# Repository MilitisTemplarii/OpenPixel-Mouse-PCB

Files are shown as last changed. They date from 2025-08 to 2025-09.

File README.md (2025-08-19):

# OpenPixel
# Mouse-PCB-STM32-PAW3395
BOM file soon :D

This is a mouse pcb based on stm32f215, usb3300 and paw3395

NO CODE, FIRMWARE, SOFTWARE, ETC, just a pcb design for hobby.

pcb1

pcb3

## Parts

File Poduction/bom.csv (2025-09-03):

Designator | Footprint | Quantity | Value | LCSC Part #
C1, C5, C7 | 805 | 3 | 10 uF
C2, C30, C31, C33, C38, C39, C4, C40, C41, C42, C43, C44, C45, C46, C48, C49, C50, C51, C52, C6, C8, C9 | 402 | 22 | 100 nF
C24, C25, C28, C29 | 402 | 4 | 1 µF
C26, C27 | 402 | 2 | 2.2 uF
C3, C47 | 603 | 2 | 4,7 uF
DEBUG1 | JST_PH_S4B-PH-K_1x04_P2.00mm_Horizontal | 1 | Conn_01x04_Pin
LED_DPI1 | LED_RGB_1210 | 1 | SB1210WC01-RGB
PAW3395 | PAW3395_LGA16_fixed | 1 | ~
R1 | 603 | 1 | 5,6 Ω
R10 | 603 | 1 | 330 Ω
R11 | 603 | 1 | 100 Ω
R12, R13 | 603 | 2 | 10 kΩ
R14 | 603 | 1 | 10 kΩ
R2, R6 | 603 | 2 | 22 Ω
R3, R7, R8 | 603 | 3 | 10kΩ
R4 | 603 | 1 | 12kΩ
R5 | 603 | 1 | 820Ω
R9 | 603 | 1 | 220 Ω
SCROLL1 | Encoder_Kailh_Wheel_3Pin | 1 | CEN981012R24
SW1, SW_DPI1 | SW_SPST_TL3342 | 2 | SW_Push
SW2 | SW_SPST_EVQP7C | 1 | SW_Push
SW_LAT1 | JST_SH_BM03B-SRSS-TB_1x03-1MP_P1.00mm_Vertical | 1 | Conn_01x03_Pin
SW_LEFT1, SW_RIGHT1, SW_WHEEL1 | SW_D2FC_OMR | 3 | SW_SPDT_321
SW_POLLING1 | SSSS213202_AAL | 1 | SSSS213202
U1 | SOT-23-5 | 1 | AP2112K-3.3
U2 | SOT-23-5 | 1 | TLV75519PDBV
U4 | LQFP-64_10x10mm_P0.5mm | 1 | STM32F215RGTx
U5 | QFN-32-1EP_5x5mm_P0.5mm_EP3.45x3.45mm | 1 | USB3300-EZK
USB1 | JST_PH_S5B-PH-K_1x05_P2.00mm_Horizontal | 1 | Conn_01x05_Pin
Y2 | Oscillator_SMD_24MHz_2.5x2.0mm | 1 | OT252024MJBA4SL
Y3 | Oscillator_SMD_8MHz_2.5x2.0mm | 1 | OT3EL89CJI-111YLC-8M

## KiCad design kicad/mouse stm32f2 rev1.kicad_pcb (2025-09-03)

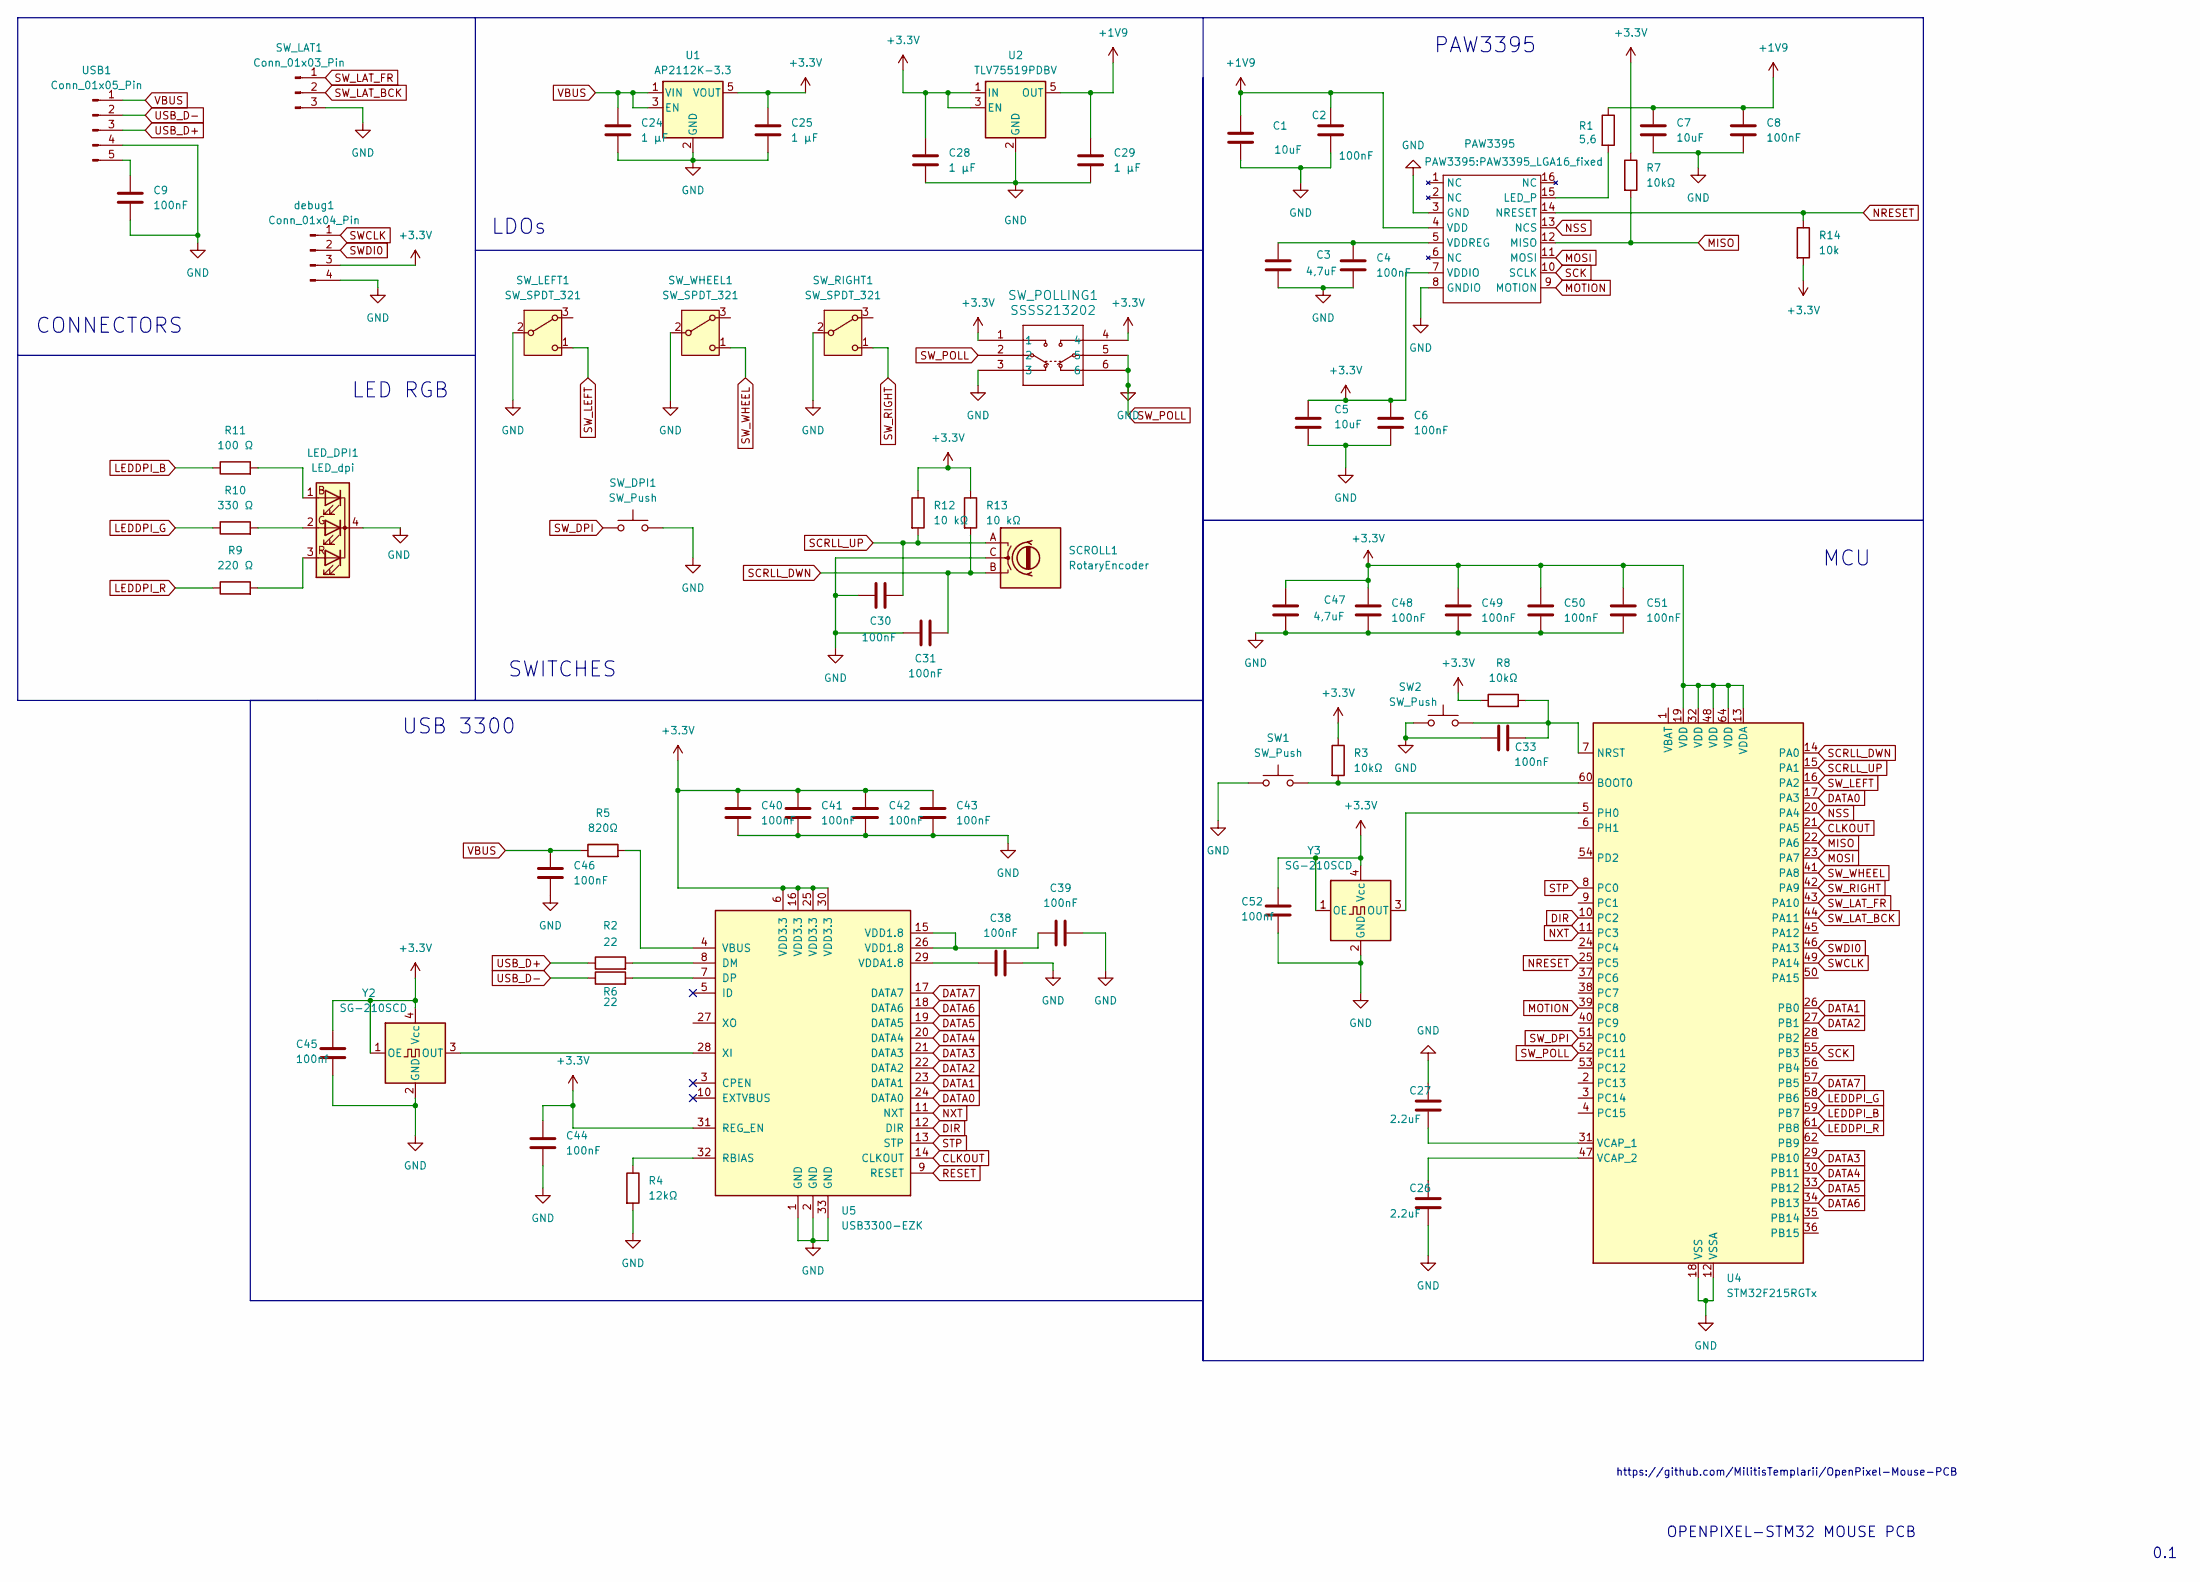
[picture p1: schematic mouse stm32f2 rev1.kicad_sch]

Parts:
C1, C5, C7: 10uF; C_0805_2012Metric
C2, C4, C6, C8, C9, C30, C31, C33, C38, C39, C40, C41, C42, C43, C44, C46, C48, C49, C50, C51: 100nF; C_0402_1005Metric
C3, C47: 4,7uF; C_0603_1608Metric
C24, C25, C28, C29: 1 µF; C_0402_1005Metric
C26, C27: 2.2uF; C_0402_1005Metric
C45, C52: 100nf; C_0402_1005Metric
LED_DPI1: LED_dpi; LED_RGB_1210
PAW3395: PAW3395_LGA16_fixed
R1: 5,6; R_0603_1608Metric
R2, R6: 22; R_0603_1608Metric
R3, R7, R8: 10kΩ; R_0603_1608Metric
R4: 12kΩ; R_0603_1608Metric
R5: 820Ω; R_0603_1608Metric
R9: 220 Ω; R_0603_1608Metric
R10: 330 Ω; R_0603_1608Metric
R11: 100 Ω; R_0603_1608Metric
R12, R13: 10 kΩ; R_0603_1608Metric
R14: 10k; R_0603_1608Metric
SCROLL1: RotaryEncoder; Encoder_Kailh_Wheel_3Pin
SW1: SW_Push; SW_SPST_TL3342
SW2: SW_Push; SW_SPST_EVQP7C
SW_DPI1: SW_Push; SW_SPST_TL3342
SW_LAT1: Conn_01x03_Pin; JST_SH_BM03B-SRSS-TB_1x03-1MP_P1.00mm_Vertical
SW_LEFT1: SW_SPDT_321; SW_D2FC_OMR
SW_POLLING1: SSSS213202; SSSS213202_AAL
SW_RIGHT1: SW_SPDT_321; SW_D2FC_OMR
SW_WHEEL1: SW_SPDT_321; SW_D2FC_OMR
U1: AP2112K-3.3; SOT-23-5
U2: TLV75519PDBV; SOT-23-5
U4: STM32F215RGTx; LQFP-64_10x10mm_P0.5mm
U5: USB3300-EZK; QFN-32-1EP_5x5mm_P0.5mm_EP3.45x3.45mm
USB1: Conn_01x05_Pin; JST_PH_S5B-PH-K_1x05_P2.00mm_Horizontal
Y2, Y3: SG-210SCD; Oscillator_SMD_SeikoEpson_SG210-4Pin_2.5x2.0mm
debug1: Conn_01x04_Pin; JST_PH_S4B-PH-K_1x04_P2.00mm_Horizontal

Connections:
+1V9: C1.1, C2.1, C7.1, C8.1, C29.1, PAW3395.4 (VDD), R1.1, U2.5 (OUT)
+3.3V: C5.1, C6.1, C25.1, C28.1, C40.1, C41.1, C42.1, C43.1, C44.1, C45.2, C47.1, C48.1, C49.1, C50.1, C51.1, C52.2, PAW3395.7 (VDDIO), R3.1, R7.1, R8.1, R12.1, R13.1, R14.2, SW_POLLING1.1, SW_POLLING1.4, U1.5 (VOUT), U2.1 (IN), U2.3 (EN), U4.13 (VDDA), U4.19 (VDD), U4.32 (VDD), U4.48 (VDD), U4.64 (VDD), U5.6 (VDD3.3), U5.16 (VDD3.3), U5.25 (VDD3.3), U5.30 (VDD3.3), U5.31 (REG_EN), Y2.1 (OE), Y2.4 (Vcc), Y3.1 (OE), Y3.4 (Vcc), debug1.3
CLKOUT: U4.21 (PA5), U5.14 (CLKOUT)
DATA0: U4.17 (PA3), U5.24 (DATA0)
DATA1: U4.26 (PB0), U5.23 (DATA1)
DATA2: U4.27 (PB1), U5.22 (DATA2)
DATA3: U4.29 (PB10), U5.21 (DATA3)
DATA4: U4.30 (PB11), U5.20 (DATA4)
DATA5: U4.33 (PB12), U5.19 (DATA5)
DATA6: U4.34 (PB13), U5.18 (DATA6)
DATA7: U4.57 (PB5), U5.17 (DATA7)
DIR: U4.10 (PC2), U5.12 (DIR)
LEDDPI_B: R11.1, U4.59 (PB7)
LEDDPI_G: R10.1, U4.58 (PB6)
LEDDPI_R: R9.1, U4.61 (PB8)
MISO: PAW3395.12 (MISO), R7.2, U4.22 (PA6)
MOSI: PAW3395.11 (MOSI), U4.23 (PA7)
MOTION: PAW3395.9 (MOTION), U4.39 (PC8)
NRESET: PAW3395.14 (NRESET), R14.1, U4.25 (PC5)
NSS: PAW3395.13 (NCS), U4.20 (PA4)
NXT: U4.11 (PC3), U5.11 (NXT)
unnamed: C39.1, U5.15 (VDD1.8), U5.26 (VDD1.8)
unnamed: LED_DPI1.1 (BA), R11.2
unnamed: LED_DPI1.2 (GA), R10.2
unnamed: LED_DPI1.3 (RA), R9.2
unnamed: PAW3395.15 (LED_P), R1.2
unnamed: C3.1, C4.1, PAW3395.5 (VDDREG)
unnamed: R3.2, SW1.2, U4.60 (BOOT0)
unnamed: C33.2, R8.2, SW2.2, U4.7 (NRST)
unnamed: U4.5 (PH0), Y3.3 (OUT)
unnamed: C27.2, U4.31 (VCAP_1)
unnamed: C26.1, U4.47 (VCAP_2)
unnamed: R2.2, U5.8 (DM)
unnamed: R6.2, U5.7 (DP)
unnamed: R4.1, U5.32 (RBIAS)
unnamed: R5.2, U5.4 (VBUS)
unnamed: C38.1, U5.29 (VDDA1.8)
unnamed: U5.28 (XI), Y2.3 (OUT)
unnamed: C9.1, USB1.5
RESET: U5.9 (RESET)
SCK: PAW3395.10 (SCLK), U4.55 (PB3)
SCRLL_DWN: C31.2, R13.2, SCROLL1.B, U4.14 (PA0)
SCRLL_UP: C30.2, R12.2, SCROLL1.A, U4.15 (PA1)
STP: U4.8 (PC0), U5.13 (STP)
SWCLK: U4.49 (PA14), debug1.1
SWDI0: U4.46 (PA13), debug1.2
SW_DPI: SW_DPI1.1, U4.51 (PC10)
SW_LAT_BCK: SW_LAT1.2, U4.44 (PA11)
SW_LAT_FR: SW_LAT1.1, U4.43 (PA10)
SW_LEFT: SW_LEFT1.1 (C), U4.16 (PA2)
SW_RIGHT: SW_RIGHT1.1 (C), U4.42 (PA9)
SW_WHEEL: SW_WHEEL1.1 (C), U4.41 (PA8)
USB_D+: R2.1, USB1.3
USB_D-: R6.1, USB1.2
VBUS: C24.1, C46.2, R5.1, U1.1 (VIN), U1.3 (EN), USB1.1

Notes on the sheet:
USB 3300
PAW3395
0.1
MCU
https://github.com/MilitisTemplarii/OpenPixel-Mouse-PCB
SWITCHES
LDOs
CONNECTORS
OPENPIXEL-STM32 MOUSE PCB
LED RGB

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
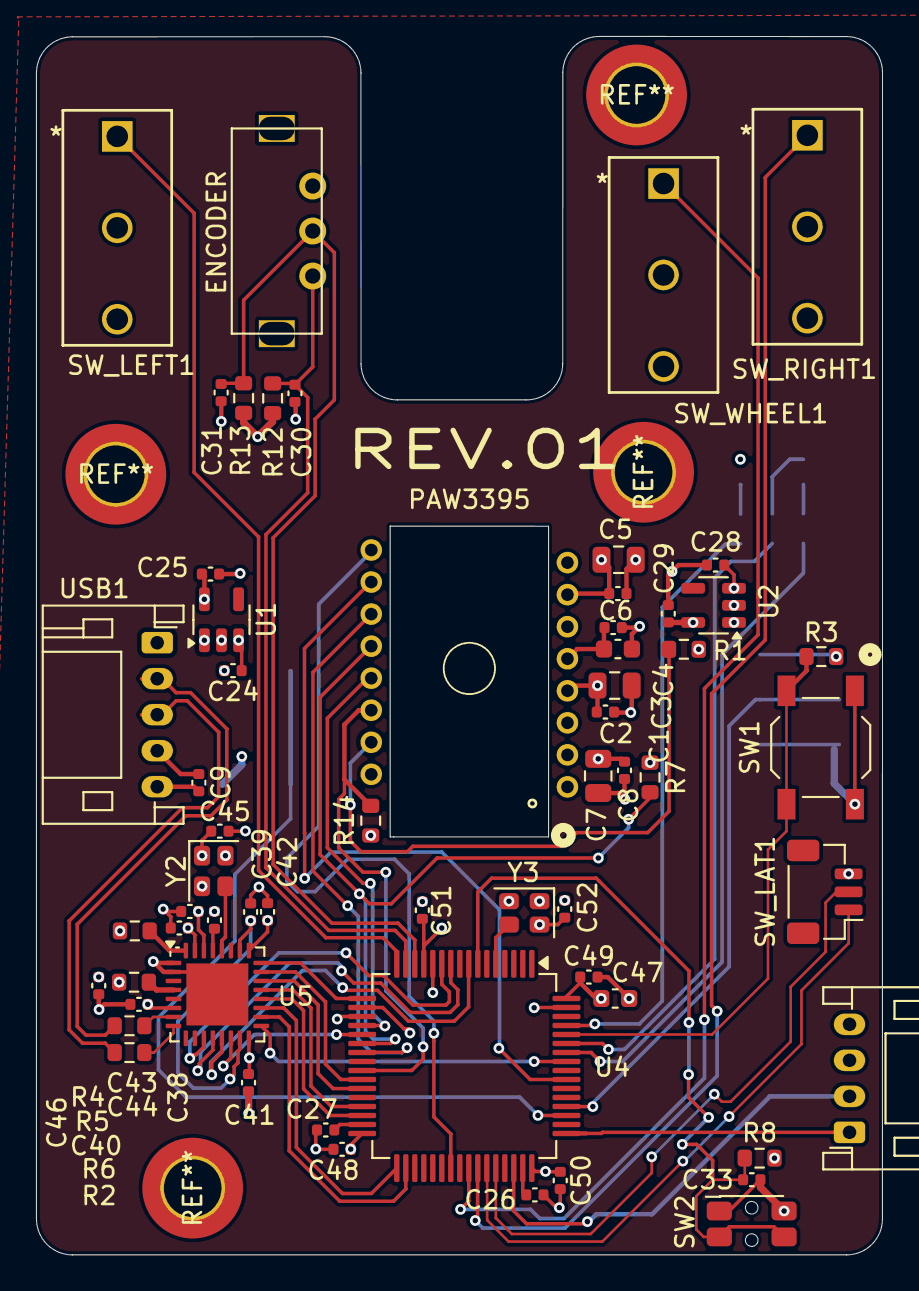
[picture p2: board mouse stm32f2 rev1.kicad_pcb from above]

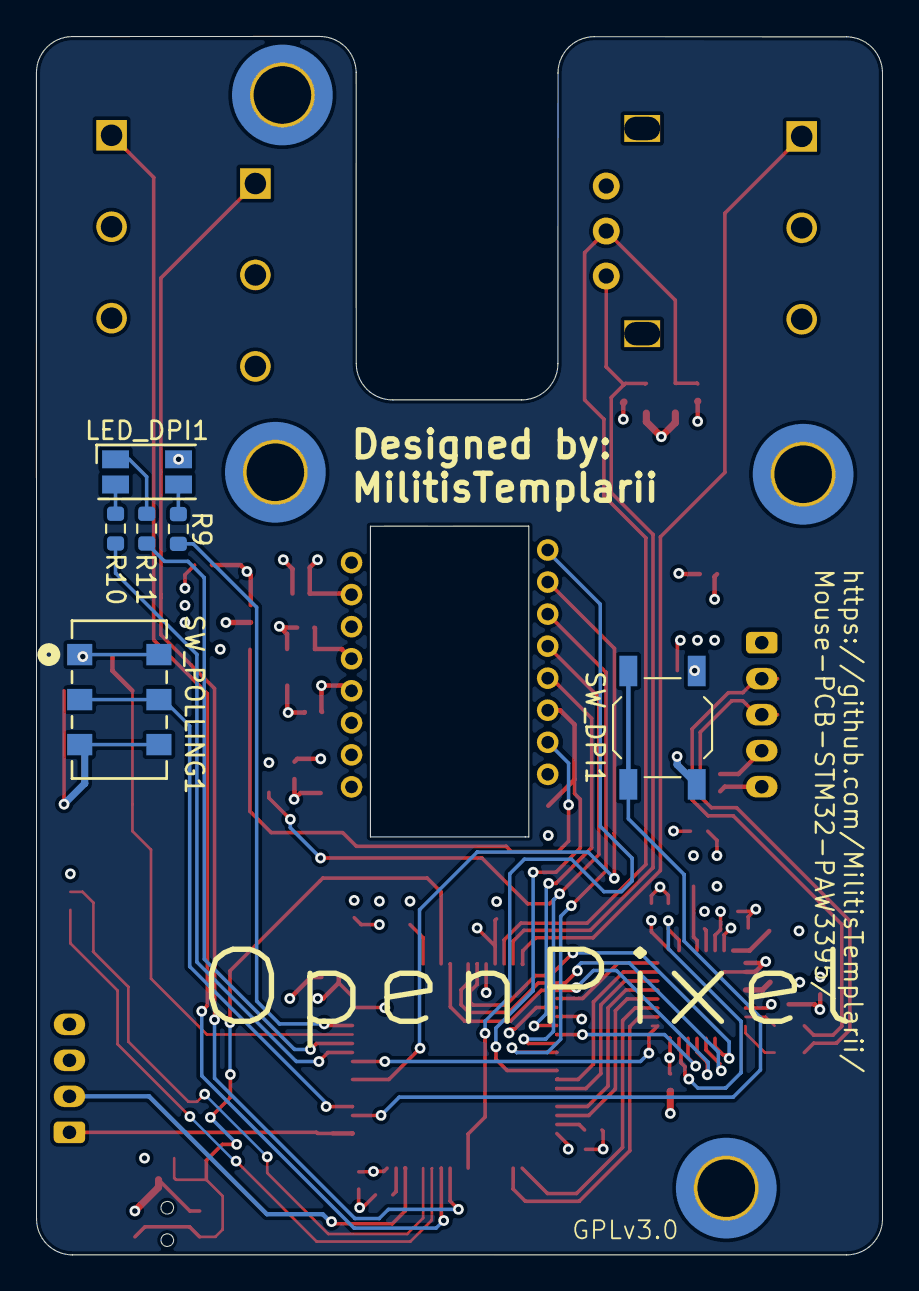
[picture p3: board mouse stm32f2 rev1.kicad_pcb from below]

Board: 4 copper layers, 47.0 x 67.7 mm, 66 parts (6 on the bottom side), 56 nets.

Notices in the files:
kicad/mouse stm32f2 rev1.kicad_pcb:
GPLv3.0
